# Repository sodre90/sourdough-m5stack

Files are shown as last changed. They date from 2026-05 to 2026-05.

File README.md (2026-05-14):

# Smart Sourdough Lid

A 3D-printed smart lid for a Weck 580ml jar that monitors sourdough starter rise, temperature, humidity, and pressure — reporting to Home Assistant via ESPHome.

## Bill of Materials

| Component | Part | Note |
|---|---|---|
| Controller & Display | M5Stack Core Ink | ESP32 + 1.54" e-ink display + 390mAh battery |
| Env Sensor | M5Stack ENV III Unit | SHT30 (temp/hum) + QMP6988 (pressure), Grove |
| Distance Sensor | M5Stack VL53L0X Unit | Time-of-flight, Grove |
| Hub | M5Stack 1-to-3 HUB Expansion Unit | Splits one Grove port into three |
| Enclosure | 3D Printed Lid (single piece) | PETG recommended, see `lid/lid.blend` |

No screws or additional hardware needed.

## Wiring

All sensors are I2C over Grove cables through the HUB.

```
Core Ink Grove port
       |
       |  Grove cable
       v
  +----------+
  | 1-to-3   |
  |   HUB    |
  +--+---+---+
     |   |   +--- port 3: free (future expansion)
     |   |
     |   +-------- port 2: Grove cable -> ENV III
     |
     +------------ port 1: Grove cable -> VL53L0X
```

| Connection | I2C Address |
|---|---|
| Core Ink Grove -> HUB -> ENV III (SHT30) | 0x44 |
| Core Ink Grove -> HUB -> ENV III (QMP6988) | 0x70 |
| Core Ink Grove -> HUB -> VL53L0X | 0x29 |

Grove uses GPIO32 (SDA) / GPIO33 (SCL) on the Core Ink.

## 3D Printed Enclosure

The lid is a single monolithic piece — a Blender model in `lid/lid.blend` (exported as `lid/lid.stl`).

| Top (component pockets) | Bottom (sensor recesses) | Side profile |
|---|---|---|
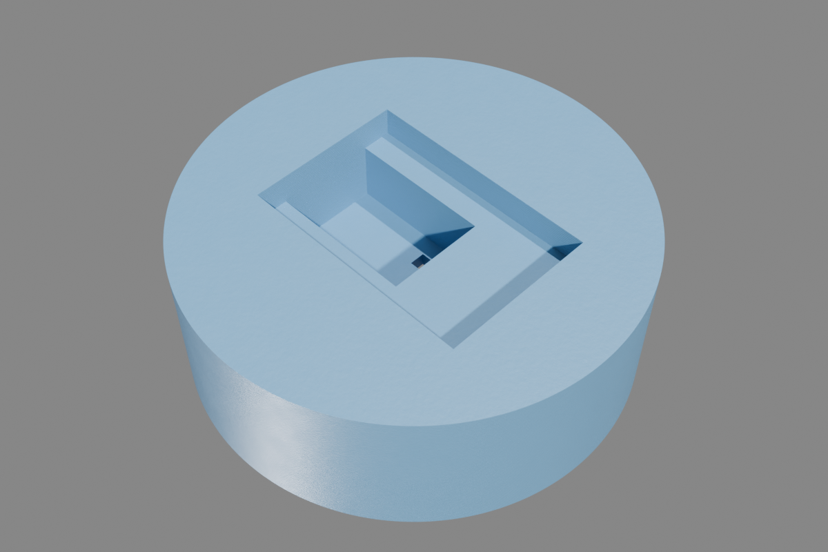
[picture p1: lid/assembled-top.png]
Top view
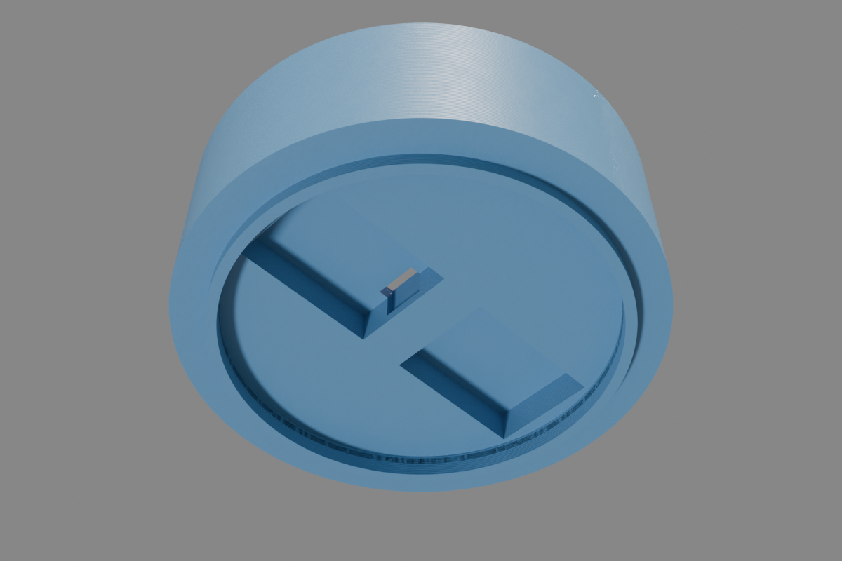
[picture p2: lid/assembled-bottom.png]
Bottom view
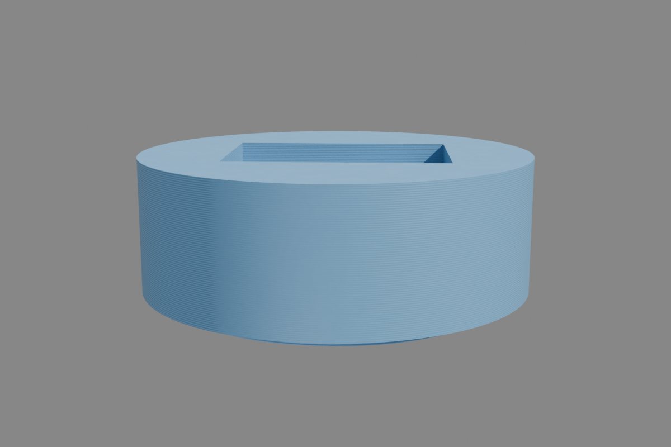
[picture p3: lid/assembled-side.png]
Side view
|  |  |  |

- **Top side**: Separate pockets for M5Stack Core Ink (display up) and 1-to-3 HUB, connected by a cable channel with Grove connector clearance
- **Bottom side**: Flat 100mm disc that replaces the glass Weck lid. VL53L0X and ENV III sensors are recessed flush into the bottom surface with snap tabs (leaving the Grove port side clear for cables)
- **Cable routing**: Through-base cable channels with Grove connector clearance connect the bottom sensor pockets to the top side
- **Rim**: 3mm clip ledge around the disc edge for the Weck metal clips

### Print settings

- Material: PETG (food-adjacent, heat resistant)
- Layer height: 0.2mm
- Infill: 20%
- Supports: none needed
- Orientation: right-side up (flat bottom on print bed)

## Assembly

1. Slide **VL53L0X** into the center pocket on the bottom (snaps in, aperture faces into the jar)
2. Slide **ENV III** into the offset pocket on the bottom (snaps in)
3. Route Grove cables up through the **cable channels** to the top side
4. Place the lid on the jar with the **rubber gasket**, clip the two **Weck metal clips** onto the rim
5. Plug both sensor cables into the **1-to-3 HUB**, plug the HUB into the **Core Ink** Grove port
6. Drop the **Core Ink** (display up) and **HUB** into the top pockets (retaining lips keep Core Ink in place)

## Rise Tracking & Peak Detection

The lid tracks sourdough starter activity over time and detects when the starter is at peak strength — the optimal moment to use it.

### How it works

1. **Press "Feed Sourdough"** after feeding your starter — either via the Home Assistant dashboard button, or by navigating to page 3 on the e-ink display and pressing the center button. This captures the baseline distance to the dough surface
2. The VL53L0X ToF sensor measures distance to the dough every 60 seconds
3. **Rise %** is calculated as `(baseline − current_distance) / initial_dough_height × 100`, where `initial_dough_height = jar_depth − baseline_distance` — so it knows the starting dough thickness and measures how much it expanded
4. **Rise rate** (mm/min, smoothed over 5 readings) shows how fast the starter is growing
5. **Peak detection** fires when the starter begins falling back after rising at least 10mm — this is when it was strongest

### Entities in Home Assistant

| Entity | Type | Description |
|---|---|---|
| Sourdough Temperature | sensor | °C from SHT30 |
| Sourdough Humidity | sensor | %RH from SHT30 |
| Sourdough Pressure | sensor | hPa from QMP6988 |
| Sourdough Distance | sensor | mm from VL53L0X to dough surface (readings >2000mm filtered as invalid) |
| Sourdough Rise | sensor | Rise % since last feed |
| Sourdough Rise Rate | sensor | mm/min, 5-reading moving average |
| Sourdough Peaked | binary_sensor | Turns on when starter passes peak |
| Battery Voltage | sensor | V from ADC on GPIO35 (×2 voltage divider) |
| Battery Percent | sensor | Estimated % (3.0–4.2V range) |
| Feed Sourdough | button | Resets baseline for a new feeding cycle |
| Jar Depth | number | mm from sensor to jar bottom (measure and set once) |

### Home Assistant automation example

```yaml
automation:
  - alias: "Sourdough peaked notification"
    trigger:
      - platform: state
        entity_id: binary_sensor.sourdough_peaked
        to: "on"
    action:
      - service: notify.mobile_app_your_phone
        data:
          title: "Sourdough Ready!"
          message: "Your starter has peaked at {{ states('sensor.sourdough_rise') }}% rise."
```

### Setup

1. Flash the firmware (see below)
2. In Home Assistant, set **Jar Depth** to the distance in mm from the ToF sensor face to the bottom of your jar (measure with a ruler)
3. After feeding your starter, press **Feed Sourdough** to begin tracking

## ESPHome Configuration

See [`sourdough-lid.yaml`](sourdough-lid.yaml) for the full configuration.

### Sensor notes

- **ENV III** contains two chips: `sht3xd` (temp + humidity) and `qmp6988` (pressure) — each needs its own sensor block.
- **Display** uses `waveshare_epaper` platform with model `1.54inv2`. SPI is on Core Ink's internal pins (CLK=GPIO18, MOSI=GPIO23); CS=GPIO9, DC=GPIO15, BUSY=GPIO4, RST=GPIO16. Battery percentage is shown in the header; pressing the top button forces a sensor refresh.
- **Battery** is read via ADC on GPIO35 through a ×2 voltage divider. The percentage is a linear map from 3.0V (empty) to 4.2V (full).

### Flashing

```bash
# Validate config
esphome config sourdough-lid.yaml

# Compile + flash over USB (first time)
esphome run sourdough-lid.yaml

# OTA update (after initial flash)
esphome run sourdough-lid.yaml --device sourdough-lid.local
```

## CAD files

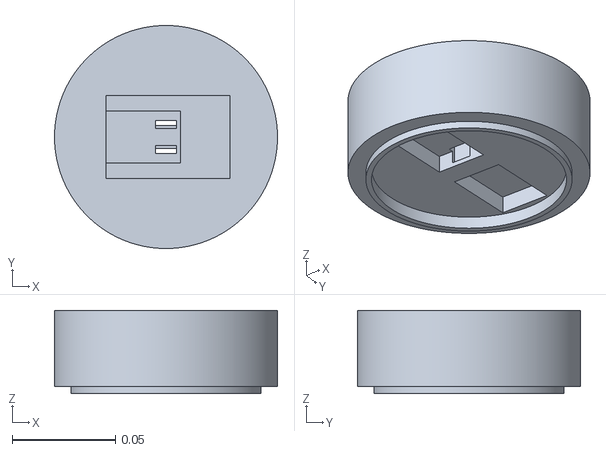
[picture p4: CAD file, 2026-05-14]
lid/lid.stl
0.108 x 0.108 x 0.0404

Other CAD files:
lid/lid.blend

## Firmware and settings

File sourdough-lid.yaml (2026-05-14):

esphome:
  name: sourdough-lid
  friendly_name: Sourdough Lid
  on_boot:
    then:
      - output.turn_on: power_hold

esp32:
  board: m5stack-coreink
  framework:
    type: arduino

output:
  - platform: gpio
    id: power_hold
    pin: GPIO12

wifi:
  ssid: !secret wifi_ssid
  password: !secret wifi_password

api:
logger:
ota:
  platform: esphome

# ─── State tracking ──────────────────────────────────────────
globals:
  - id: baseline_distance
    type: float
    restore_value: yes
    initial_value: '0'
  - id: prev_distance
    type: float
    restore_value: no
    initial_value: '-1'
  - id: min_distance
    type: float
    restore_value: yes
    initial_value: '9999'
  - id: peak_notified
    type: bool
    restore_value: yes
    initial_value: 'false'
  - id: current_page
    type: int
    restore_value: no
    initial_value: '0'

# ─── Configuration ───────────────────────────────────────────
number:
  - platform: template
    name: "Jar Depth"
    id: jar_depth
    unit_of_measurement: "mm"
    min_value: 50
    max_value: 200
    step: 1
    initial_value: 110
    restore_value: true
    optimistic: true
    entity_category: config
    icon: "mdi:cup-outline"

# ─── Bus ─────────────────────────────────────────────────────
i2c:
  sda: GPIO32
  scl: GPIO33
  scan: true

# ─── Sensors ─────────────────────────────────────────────────
sensor:
  # ENV III — SHT30: temperature + humidity
  - platform: sht3xd
    id: sht30
    address: 0x44
    update_interval: 60s
    temperature:
      name: "Sourdough Temperature"
      id: sourdough_temp
    humidity:
      name: "Sourdough Humidity"
      id: sourdough_hum

  # ENV III — QMP6988: barometric pressure
  - platform: qmp6988
    id: qmp6988_sensor
    address: 0x70
    update_interval: 60s
    pressure:
      name: "Sourdough Pressure"
      id: sourdough_pressure

  # VL53L0X: distance to dough surface (mm)
  - platform: vl53l0x
    name: "Sourdough Distance"
    id: sourdough_distance
    update_interval: 60s
    unit_of_measurement: "mm"
    filters:
      - multiply: 1000
      - lambda: 'return x > 2000 ? NAN : x;'
    on_value:
      then:
        - lambda: |-
            float dist = x;
            float baseline = id(baseline_distance);

            // Rise rate: positive = dough rising (distance shrinking)
            if (id(prev_distance) > 0) {
              id(sourdough_rise_rate).publish_state(id(prev_distance) - dist);
            }

            if (baseline > 0) {
              float rise_mm = baseline - dist;

              // Rise percentage relative to initial dough height
              float initial_height = id(jar_depth).state - baseline;
              if (initial_height > 0) {
                id(sourdough_rise_pct).publish_state((rise_mm / initial_height) * 100.0f);
              }

              // Track closest approach (maximum rise)
              if (dist < id(min_distance)) {
                id(min_distance) = dist;
              }

              // Peak: starter falling back after rising at least 10mm,
              // current distance 5mm above the peak (hysteresis against noise)
              if (!id(peak_notified) && rise_mm > 10.0f && dist > id(min_distance) + 5.0f) {
                id(peak_notified) = true;
                id(sourdough_peaked).publish_state(true);
              }
            }

            id(prev_distance) = dist;

  # Battery voltage via ADC (20k/5.1k voltage divider)
  - platform: adc
    pin: GPIO35
    name: "Battery Voltage"
    id: battery_voltage
    unit_of_measurement: "V"
    update_interval: 30s
    attenuation: 6db
    filters:
      - multiply: 4.92157  # Changed from 2.0
      - median:
          window_size: 10
          send_every: 10
      - lambda: |-
          if (x < 2.8) return 2.8f; else if (x > 4.35) return 4.35f; else return x;
    on_value:
      then:
        - component.update: battery_pct

  - platform: template
    name: "Battery Percent"
    id: battery_pct
    unit_of_measurement: "%"
    accuracy_decimals: 0
    icon: "mdi:battery"
    update_interval: 60s
    lambda: |-
      float v = id(battery_voltage).state;
      if (isnan(v) || v < 0.1f) return NAN;
      float pct = (v - 3.0f) / (4.2f - 3.0f) * 100.0f;
      if (pct > 100.0f) pct = 100.0f;
      if (pct < 0.0f) pct = 0.0f;
      return pct;

  # Derived: rise percentage since feeding
  - platform: template
    name: "Sourdough Rise"
    id: sourdough_rise_pct
    unit_of_measurement: "%"
    accuracy_decimals: 0
    icon: "mdi:arrow-expand-up"

  # Derived: rise rate (mm/min, smoothed over 5 readings)
  - platform: template
    name: "Sourdough Rise Rate"
    id: sourdough_rise_rate
    unit_of_measurement: "mm/min"
    accuracy_decimals: 1
    icon: "mdi:trending-up"
    filters:
      - sliding_window_moving_average:
          window_size: 5
          send_every: 1
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

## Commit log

2026-05-12 Initial commit: smart sourdough lid for Weck jar
    - ESPHome config for M5Stack Core Ink + ENV III + VL53L0X sensors
    - Parametric OpenSCAD lid model (single piece, no screws)
    - Assembly instructions and wiring diagram in README
    [sourdough-lid.scad]
2026-05-13 Add rise tracking, peak detection, and feed button
    - Rise % sensor (relative to initial dough height)
    - Rise rate sensor (mm/min, 5-reading moving average)
    - Peak detection binary sensor (10mm min rise, 5mm hysteresis)
    - Feed Sourdough button to reset baseline
    - Configurable jar depth number entity
    - E-ink display shows rise status and peak alert
    - README documents new entities and HA automation example
    [sourdough-lid.yaml]
2026-05-13 Fix Core Ink pins, add dial menu, larger fonts
    - Board: m5stack-coreink (was esp32dev)
    - I2C: GPIO32/GPIO33 (was GPIO21/GPIO22)
    - Display: reset=GPIO0, busy inverted, correct model
    - 3-page dial menu: Status, Details, Feed
    - Larger fonts (18/32/52px) for e-ink readability
    - NaN guard for initial sensor readings
    - Full display refresh to prevent e-ink ghosting
    - .gitignore: add .esphome/ and .DS_Store
    [sourdough-lid.yaml]
2026-05-13 Redesign lid: separate pockets with Grove cable clearance
    - Split single cavity into separate Core Ink and HUB pockets
    - Added cable channel (10mm wide) between pockets for Grove cable
    - Added grove_cl (6mm) parameter for connector clearance
    - Through-base cable channels from sensor pockets to top side
    - Sensor snap tabs leave Grove port side (+Y) clear for cables
    - Core Ink retaining lips on both ±Y edges
    - Shifted model so bottom edge sits at Y=0
    - Spread components apart: Core Ink at Y=17, HUB at Y=-28
    - Sensors repositioned: ToF at (0,-5), ENV III at (0,-25)
    [sourdough-lid.scad]
2026-05-13 Add battery monitoring, improve display layout and sensor reliability
    Battery:
    - Add ADC sensor on GPIO35 for battery voltage (×2 divider)
    - Add template sensor for battery percentage (3.0–4.2V range)
    - Show battery percentage on e-ink display next to page dots
    Display:
    - Add STATUS header with divider line on page 0
    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
2026-05-13 Update README: Grove cable clearance, battery monitoring, sensor filtering
2026-05-13 Re-render assembled view PNGs for redesigned lid
2026-05-13 README: mention physical button feed action on page 3
2026-05-13 Hold GPIO12 HIGH on boot for battery power
    M5Stack Core Ink requires GPIO12 to be driven HIGH to keep the
    internal power rail active when running from battery. Without this,
    the device powers off immediately after the boot button is released.
    Added a gpio output (power_hold) on GPIO12 and an on_boot action
    that turns it on before anything else runs.
2026-05-13 Skip battery percent update until ADC has a valid reading
    Return empty optional instead of 0% when battery voltage is NaN
    or near-zero, so the sensor stays unknown until real data arrives.
    [sourdough-lid.yaml]
2026-05-13 Fix battery percent: update on ADC read, skip until valid
    - battery_pct now recalculates immediately when battery_voltage
    publishes via on_value trigger (no stale 0% on boot)
    - Return NAN instead of 0 when ADC has no reading yet
    - Include battery_pct in button-press sensor refresh
    [sourdough-lid.yaml]
2026-05-13 Show battery voltage alongside percentage on display
2026-05-13 Add through-base cable entry hole in HUB pocket floor
    Cables from bottom sensors had no direct path into the HUB pocket —
    the through-base channels from sensors emerged into the inter-pocket
    channel but the HUB floor was solid. Added a cable_ch_w × grove_cl
    slot through the base at the +Y side of the HUB pocket.
    [sourdough-lid.scad]
2026-05-14 Replace OpenSCAD with Blender model and re-render lid images
    - Remove lid/sourdough-lid.scad
    - Add lid/lid.blend (Blender source) and lid/render.py (headless renderer)
    - Re-render assembled-top/side/bottom PNGs from STL via Cycles
    - Update README.md and CLAUDE.md to reference Blender instead of OpenSCAD
    - Add *.blend1 to .gitignore
    [lid.blend, sourdough-lid.scad]
2026-05-14 Update ADC config: improve battery voltage measurement accuracy
    - Adjust attenuation to 6db and update interval to 30s
    - Replace multiplier with precise 4.92157 factor
    - Apply median filter and lambda for clamping valid voltage range
    - Update corresponding lid images and Blender source
    [lid.blend, lid.stl]
